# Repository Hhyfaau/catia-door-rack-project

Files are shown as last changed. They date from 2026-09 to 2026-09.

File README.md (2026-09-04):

# 汽车车门转运车架（CATIA V5 课程项目）

本项目为 CATIA V5 产品设计课程作业：**汽车车门转运车架**（焊接方管框架），用于汽车门板的立式存放与转运。

## 目录说明

| 目录 | 内容 |
|---|---|
| `CAD/` | CATIA 装配 `DoorRack3.CATProduct` 及所用 11 种零件的 `.CATPart` |
| `report/` | CATIA 产品设计报告（Word） |
| `images/` | 总装配等轴测截图、A3 工程图图样 |
| `step/` | 总装配 STEP 汇总文件 |

## 主要参数

- 总体：长 2400 × 宽 1000 × 高 800 mm（含门架总高 1113）
- 空心方管：40×40×2.5
- 顶部纵向梁：11 根，宽向间距 20cm
- 立柱：13 根（4 根角柱带把手）
- V 型定位小梁：10 根
- 门架支撑单元：8 个（U 型梁 580 + 双立柱，高 153）
- 端部水平方管：2 根，40×153×250

## 软件

- CATIA V5 （R20+）

## 项目技能（Codex Skill）

仓库内置一个 Codex 技能：**`catia-door-rack`**。它是一个"说明书"，让 AI 助手（Codex/Claude）能在这个项目上自动完成建模、修改和出图，而不用每次都从零摸索。

### 它能做什么

- **重建模型**：按项目参数一键重建整套车架（11 根顶梁、13 立柱、10 根 V 型定位梁、8 个门架、端部方管）。
- **改尺寸/位置**：改某个梁/柱/门架的尺寸或坐标（改参数，不是手动重画）。
- **加构件**：新增立柱/横梁/支撑。
- **导出**：生成 STEP、Word 报告、A3 工程图（BOM + 三视图 + 等轴测 + 零件序号）。
- **出工程图教程**：说明了在 CATIA 里用 A3 图框 + 零件序号 + BOM 的标准操作。

### 目录结构

```
catia-door-rack/
├── SKILL.md                      # 技能说明与工作流
├── agents/openai.yaml            # 技能 UI 元数据
├── references/dimensions.md      # 全部尺寸与坐标（修改时的单一事实来源）
└── scripts/                      # 建管、装配、门架、端管、导出、报告等 11 个脚本
```

### 怎么用

- 打开本项目，直接对 Codex 说："用 catia-door-rack 技能重建/修改模型"或"导出报告"。
- 想改参数：看 `references/dimensions.md`，改对应脚本里的数值，再跑对应脚本。
- 想让 AI 全局可用：把 `catia-door-rack/` 复制到 `~/.codex/skills/`。

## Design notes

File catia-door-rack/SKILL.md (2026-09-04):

---
name: catia-door-rack
description: Build, modify, regenerate, and export the CATIA V5 汽车车门转运车架 (car-door transport rack) welded-steel-frame project. Use when Codex needs to (1) rebuild the rack assembly from its scripts (11 top beams, 13 posts with corner handles, 10 V-beam door locators, 8 U-beam+post gate supports, 2 end tubes), (2) change any dimension/position or add a member, (3) regenerate the CAD part templates or assembly, (4) export a STEP, (5) generate the Word report, or (6) produce the A3 engineering drawing. Triggered by requests about this project's CATPart/CATProduct files, its build scripts under scripts/, its report (.docx), or its drawing. Also use when working in the CATIA V5 automation stack (pycatia + win32com) for hollow square-tube frames.
---

# CATIA Car-Door Transport Rack

## Overview

This skill lets an agent regenerate, modify, and export a CATIA V5 **car-door transport rack** (汽车车门转运车架) — a welded frame of hollow 40×40 square tube that stores car doors upright (each door's bottom edge drops into a V-groove). Everything is exposed as a single assembly `DoorRack3.CATProduct` composed of 11 part types, plus a Word report and an A3 engineering drawing.

It is **data-driven**: all geometry is described by scripts + a coordinates reference, so changes are parameter edits, not manual CATIA re-modeling.

## When to use

- Rebuild the whole model from scratch.
- Change a beam/post/V-beam/gate dimension or position.
- Add a new member (post, beam, connector, support).
- Regenerate the engineering drawing or the Word report.
- Export a STEP for downstream use.

## Prerequisites

- CATIA V5 running with `CATIA.Application` reachable via COM.
- Python interpreter with `pycatia`, `pywin32` (this project uses `C:\Users\Administrator\Documents\Codex\CATIClaude\.venv\Scripts\python.exe`).

## Model anatomy

| 部件 | 数量 | 说明 |
|---|---|---|
| 顶部纵向梁 | 11 | 40×40×920 空心方管，沿宽度方向 20cm 间距，形成 10 个车门存放槽 |
| 纵/横梁(顶/底) | 6 | 40×40×2360/920 空心方管，组成框架周界与内部梁 |
| 立柱 | 9 | 40×40×720 空心方管，支撑顶架 |
| 角柱(带把手) | 4 | 40×40×840，顶部伸出当作把手 |
| V 型定位小梁 | 10 | V 型截面，每槽一根，托住车门底边定位 |
| 连接短梁 | 4+2+4 | 40×40×{320,200,260}，底部 A/B/C 间隔连接梁 |
| 门架U型梁 | 8 | U 型截面 56宽×25高×3厚、长580 |
| 门架立柱 | 16 | 40×40×150，插在 U 梁内底面，顶面贴底部横梁下表面 |
| 端部水平方管 | 2 | 40×153×250 矩形空心管 |

关键装配关系：门架立柱 X 与 AC 间隔连接短梁对齐（700/1200/1700/2200）；U 型梁以两立柱中心对称；门架 U 梁底面贴地(Z=-153)、立柱顶面 Z=0 贴框架底梁下表面；总高 = 门架 153 + 框架 960。

## Workflow

1. **Rebuild** — run the builder scripts in order. They close all documents, rebuild part templates, build the assembly, place gates/end tubes.
2. **Modify** — edit the desired parameter in the corresponding script, re-run that step, then re-run dependent steps.
3. **Export** — run `scripts/export_step.py` for STEP; run `scripts/build_report.py` for the Word report; generate the A3 `.CATDrawing` in CATIA (details below).

```powershell
$py = "C:\Users\Administrator\Documents\Codex\CATIClaude\.venv\Scripts\python.exe"
& $py scripts/build_tubes.py
& $py scripts/build_assembly.py
& $py scripts/add_gate_parts.py
& $py scripts/add_endtubes.py
& $py scripts/export_step.py
& $py scripts/build_report.py
```

## Scripts

| 脚本 | 作用 |
|---|---|
| `build_tubes.py` | 建空心方管模板（外 Pad 40×40 + 内贯通 Pocket，`limit_mode=2`）与 U 梁/V 梁 |
| `build_assembly.py` | 建 `DoorRack3.CATProduct`，用"起点定位 + 旋转矩阵"放所有框架杆件 |
| `place_gates_final.py` / `add_gate_parts.py` | 加 8 个门架（U 梁+双立柱），立柱对齐 AC 短梁 X |
| `add_endtubes.py` / `build_endtubes.py` | 加 2 根端部水平方管（40×153×250） |
| `export_step.py` | 导出总装配 STEP |
| `build_report.py` | 用 python-docx 生成 Word 报告 |
| `gen_drawing2.py` / `render_iso.py` / `gen_2d_dims.py` | 生成 A3 工程图图样 / 整体轴测图 / 二维尺寸图 |

## Parameters & coordinates

All coordinates use X=length(0..2400), Y=width(±500), Z=height(0=frame bottom; gates hang to -153). The authoritative table lives in `references/dimensions.md` — treat it as the source of truth when editing, and update both the script and the reference together.

Defining rotation matrices (`position.set_components((*R, tx,ty,tz))`):

- `R_X = (0,0,-1, 0,1,0, 1,0,0)` — beam along length (X). `tx = start_x`, `ty/tz = cross center`.
- `R_Y = (-1,0,0, 0,0,1, 0,1,0)` — beam along width (Y), and makes a U-beam open upward. `ty = start_y`.
- `R_Z = (1,0,0, 0,1,0, 0,0,1)` — vertical post. `tz = start_z`.

## Engineering drawing (+BOM & balloons)

The native `.CATDrawing` must be generated in CATIA's Drafting workbench (not automatable here):

1. Open `DoorRack3.CATProduct`.
2. 文件→新建→Drawing → **A3** 纵向，比例 1:10 → 有 A3 图框/标题栏。
3. 插入 → 视图：主视图（正面长×高方向）→ 拖出俯视图/侧视图 → 再插等轴测视图，按图框调比例。
4. 插入 → 标注 → 零件序号(气球) → 在轴测图上点选零件。
5. 插入 → 表格 → BOM（材料清单）。
6. 另存为 `总装配图.CATDrawing`。

## Gotchas

- **Hollow parts** are Pad(outer) + through Pocket(inner). Must set `pkt.first_limit.limit_mode = 2`, else R20 offset pockets cut nothing.
- **Start-point positioning**, not center: for `X`/`Y` beams the translation component is the *start* of the long axis; the other two are the cross-section center.
- **File locks**: rebuilding a part file requires closing the assembly that references it, else `SaveAs` fails. Close all docs before template builds.
- **Sub-assembly links break** after many close/reopen cycles ("Check Product for broken links"). Prefer placing parts directly instead of via sub-assemblies.
- **Chinese in SKILL.md**: validate tools may read files as GBK on a zh-CN system; that's a tool limitation, not a skill defect.

## Example requests

- "Rebuild the CATIA door rack using this skill."
- "把门架 U 型梁长度改成 620，并让 8 个门架保持对称。"
- "Add 2 more support posts at X=900, Y=+480."
- "Export the assembly to STEP and regenerate the report."

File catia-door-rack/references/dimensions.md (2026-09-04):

# Dimensions & coordinates (mm)

All coordinates use X = length (0..2400), Y = width (0-centered, ±500), Z = height (0 = frame bottom; gates hang to Z=-153). Tube cross-section 40×40×2.5 (hollow).

| Member | Type | Count | Size | Position (orient, start / center) |
|---|---|---|---|---|
| 顶部纵向梁 | 空心方管 | 11 | 40×40×920 | 'Y', X=i*240, start Y=-460, Z=780 |
| 顶部横梁(无立柱侧) | 空心方管 | 1 | 40×40×2360 | 'X', start X=20, Y=-480, Z=780 |
| 底部纵梁 | 空心方管 | 2 | 40×40×2360 | 'X', X=20..2380, Y=±480, Z=20 |
| 底部内梁 | 空心方管 | 2 | 40×40×2360 | 'X', X=40..2360, Y=±120, Z=20 |
| 底部端梁 | 空心方管 | 2 | 40×40×920 | 'Y', X=0/2400, Y=-460..460, Z=20 |
| 立柱 | 空心方管 | 9 | 40×40×720 | 'Z', X=240..2160, Y=+480, Z=40..760 |
| 角柱(把手) | 空心方管 | 4 | 40×40×840 | 'Z', X={0,2400}, Y=±480, Z=40..880 |
| V 型定位小梁 | V 型 | 10 | 600 长 | 'Y', X=(i+0.5)*240, start Y=-480, vertex Z=40, opening Z=70 |
| 连接短梁 | 空心方管 | 4+2+4 | 40×40×{320,200,260} | 'Y', A:700/1200/1700/2200 (start Y=-460); B:1500/2100 (start Y=-100); C:700/1200/1700/2200 (start Y=+140), Z=20 |
| 门架U型梁 | U 型 | 8 | 56 宽×25 高×3 厚, 长580 | 'Y', X=660/1660, Z=-153..-113 |
| 门架立柱 | 空心方管 | 16 | 40×40×150 | 'Z', X={700,1200} (gate 680) & {1700,2200} (gate 1680), Y=±480, Z=-150..0 |
| 端部水平方管 | 矩形空心 | 2 | 40×153×250 | 'X', X=120..370, Y=±120, Z=-153..0 |

## Key relationships

- 顶部 11 根纵梁沿宽度分 10 个槽，每个槽一根 V 型小梁定位车门底边。
- 底部 4 根纵梁 Y=-480/-120/+120/+420（+480 为边梁），门架立柱落在其下方。
- 门架立柱 X 与 AC 间隔连接短梁对齐（700/1200/1700/2200）；U 型梁以两立柱中心对称（580 长，左右各外探 40）。
- 门架 U 型梁底面贴地 (Z=-153)，立柱插于内底面(Z=-150)，立柱顶面 Z=0 贴框架底梁下表面。
- 总装配高度 = 门架 153 + 框架 960。

## Rotation conventions

- `R_X = (0,0,-1, 0,1,0, 1,0,0)` — local Z → world X (beam along length).
- `R_Y = (-1,0,0, 0,0,1, 0,1,0)` — local Z → world Y, local Y → world +Z (U-beam opens up, beams along width).
- `R_Z = (1,0,0, 0,1,0, 0,0,1)` — vertical post.
- `position.set_components((*R, tx, ty, tz))`; for `X`/`Y`/`Z` beams t = start of the long axis, other two = cross-section center.

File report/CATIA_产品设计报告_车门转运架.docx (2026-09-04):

# CATIA 产品设计报告

产品名称：汽车车门转运车架（焊接方管框架）

# 1. 设计产品介绍

本产品是一款用于汽车制造与维修环节的汽车车门转运架（料架）。它是一台由 40×40 焊接方管构成的框架结构，用于在生产流转、仓储或装配时将多扇汽车车门立式集中存放、转运，避免车门磕碰并实现快速定位、搬运。框架下方装有带脚轮安装位的底架，整体可移动、可堆叠。

框架主要由四部分组成：①顶部承托层——11 根沿长度方向均布的纵向梁，形成 10 个车门存放槽；②中部立柱——13 根方管立柱（4 根角柱顶部伸出作把手），连接上下两层；③底部支撑架——纵梁、内梁与多道连接短梁构成的底部框架；④定位机构——每个槽底部一根 V 型小梁，车门底边落入 V 槽实现定位。框架下方另设 8 个“U 型梁+双立柱”门架支撑单元和端部水平支撑管，提高整体刚性与搬运可靠性。

# 2. 产品二维尺寸

产品主要外形尺寸如下表（单位 mm）。

项目 | 尺寸 / 数值 (mm)
总体外形（长×宽×高） | 2400 × 1000 × 800（框架；含把手高 880）
方管规格 | 40×40（空心，壁厚 2.5）
顶部纵向梁 | 11 根，40×40×2400，沿宽度方向 20cm 间距均布
立柱 | 13 根（4 根角柱带把手伸出）
V 型定位小梁 | 10 根，位于相邻纵梁中间
门架支撑单元 | 8 个；U 型梁长 580、宽56×高25、厚3；立柱高153
端部水平支撑管 | 2 根，40×153×250
总装配高度 | 门架 153 + 框架 960（按题目要求）
底部连接短梁 | A/C 间隔各 4、B 间隔 2（40×40 空心方管）

# 3. CATIA 设计零件截图

主要零件的三维截图如下（各零件均以 .CATPart 文件提交）。

框架纵梁（空心方管）—— 40×40×2400，端面为空心矩形；门架单元（U 型梁 + 双立柱）—— U 型槽 56×25×3，立柱 40×40 空心方管。

注：各零件的 CATIA 截图可在 CATIA 中逐一打开零件后按“渲染样式-带边着色 / 等轴测”截取，本报告以二维示意与装配截图配合说明。

# 4. CATIA 总装配截图

总装配体三维视图如下（共 78 个组件）。

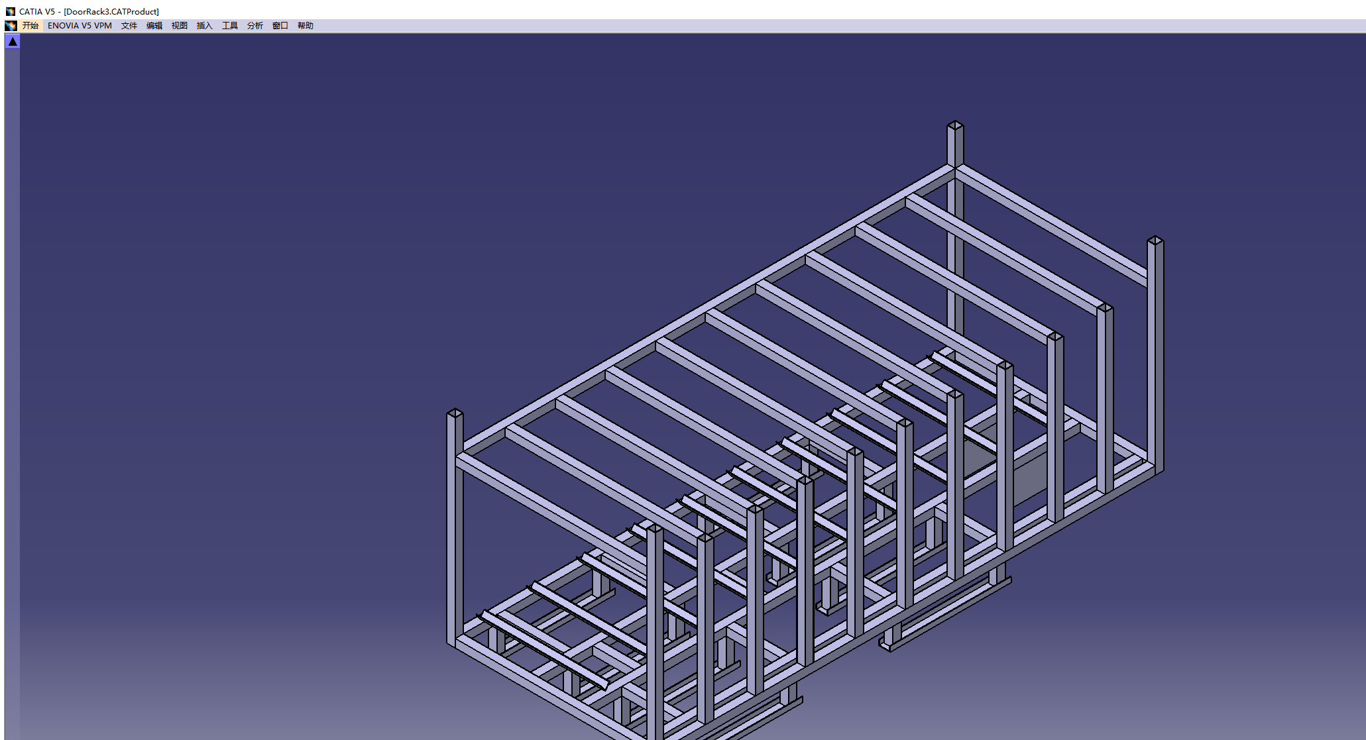
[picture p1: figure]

# 5. 总结（难点、解决与收获）

### 设计难点

① 门架 U 型梁与立柱的装配关系：要求 U 型梁底面朝下贴地、立柱插在 U 型梁内底面、立柱顶面又要与底部横梁下表面贴合，三者在长度/高度上相互约束，需反复调整；② 杆件之间的干涉：大量方管在交接处若按中心定位会互相穿透，需按“起点+精确长度+端面贴合”的方式布置；③ 层数多、零件多（78 个组件），定位与几何关系复杂。

### 解决方案

① 采用子装配/零件分别建模再装配：把立柱做成方形空心管（Pad+Pocket 打通），U 型梁用 U型截面拉伸，先做出符合要求的门架单元；② 用“按起点+长度”定位坐标，并让连接梁端面贴到相邻梁内侧面，避免穿透；③ 通过包围盒逐对校验，确保 0 干涉；④ 对装配反复检查并迭代修正（V 型小梁朝上、门架立柱对齐 AC 短梁等），最终 0 断链、0 干涉。

### 收获与体会

通过本次设计，掌握了 CATIA 参数化建模、方管/型材的拉伸成形（Pad/Pocket 打通做空心件）、零件与装配体管理、以及装配定位与干涉检查。也体会到“先理解结构、再定尺寸、最后建模”的重要性；通过不断修正培养了对工程结构布置、公差配合和工艺性的认识。零件与装配均以 .CATPart/.CATProduct/.CATDrawing 文件一并提交。

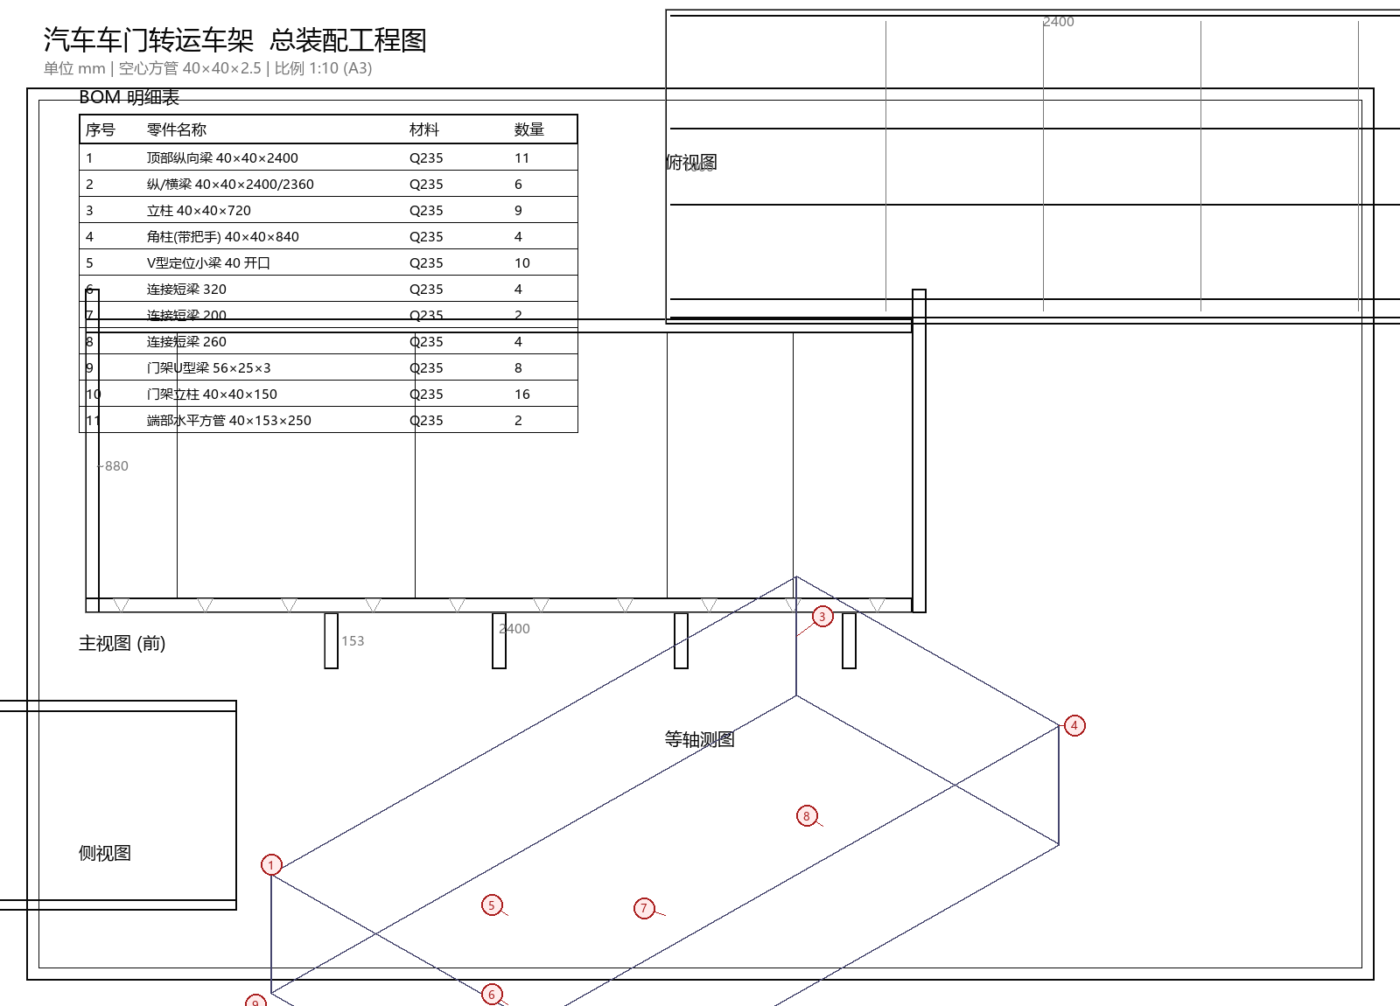
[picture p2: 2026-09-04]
images/drawing_A3.png

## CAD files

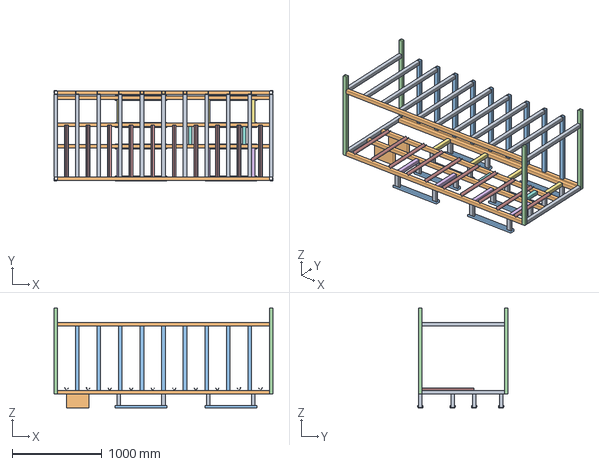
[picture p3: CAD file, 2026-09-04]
step/DoorRack3_assembly.stp
2440.0 x 1008.0 x 1113.0 mm

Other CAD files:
CAD/Beam920.CATPart
CAD/Conn200.CATPart
CAD/Conn260.CATPart
CAD/Conn320.CATPart
CAD/Corner840.CATPart
CAD/DoorRack3.CATProduct
CAD/EndTube250.CATPart
CAD/GatePost.CATPart
CAD/Post720.CATPart
CAD/Rail2360.CATPart
CAD/UBeam540.CATPart
CAD/VBeam600.CATPart

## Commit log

2026-09-04 Add CAD/Beam920.CATPart
    [Beam920.CATPart]
2026-09-04 Add CAD/Conn200.CATPart
    [Conn200.CATPart]
2026-09-04 Add CAD/Conn260.CATPart
    [Conn260.CATPart]
2026-09-04 Add CAD/Conn320.CATPart
    [Conn320.CATPart]
2026-09-04 Add CAD/Corner840.CATPart
    [Corner840.CATPart]
2026-09-04 Add CAD/DoorRack3.CATProduct
    [DoorRack3.CATProduct]
2026-09-04 Add CAD/EndTube250.CATPart
    [EndTube250.CATPart]
2026-09-04 Add CAD/GatePost.CATPart
    [GatePost.CATPart]
2026-09-04 Add CAD/Post720.CATPart
    [Post720.CATPart]
2026-09-04 Add CAD/Rail2360.CATPart
    [Rail2360.CATPart]
2026-09-04 Add CAD/UBeam540.CATPart
    [UBeam540.CATPart]
2026-09-04 Add CAD/VBeam600.CATPart
    [VBeam600.CATPart]
2026-09-04 Add images/assembly_catia.png
2026-09-04 Add step/DoorRack3_assembly.stp
    [DoorRack3_assembly.stp]
